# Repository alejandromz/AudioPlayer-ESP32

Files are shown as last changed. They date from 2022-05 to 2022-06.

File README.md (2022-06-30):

# AudioPlayer-ESP32
Proyecto Sistemas Embebidos 2022-1. La documentación del proyecto se puede encontrar en el Wiki asociado a este repositorio. En la parte del código se pueden encontrar 3 carpetas: una con el desarrollo de la placa en Kikad, otra con el código de prueba de módulos individuales y la última con el código final del proyecto.

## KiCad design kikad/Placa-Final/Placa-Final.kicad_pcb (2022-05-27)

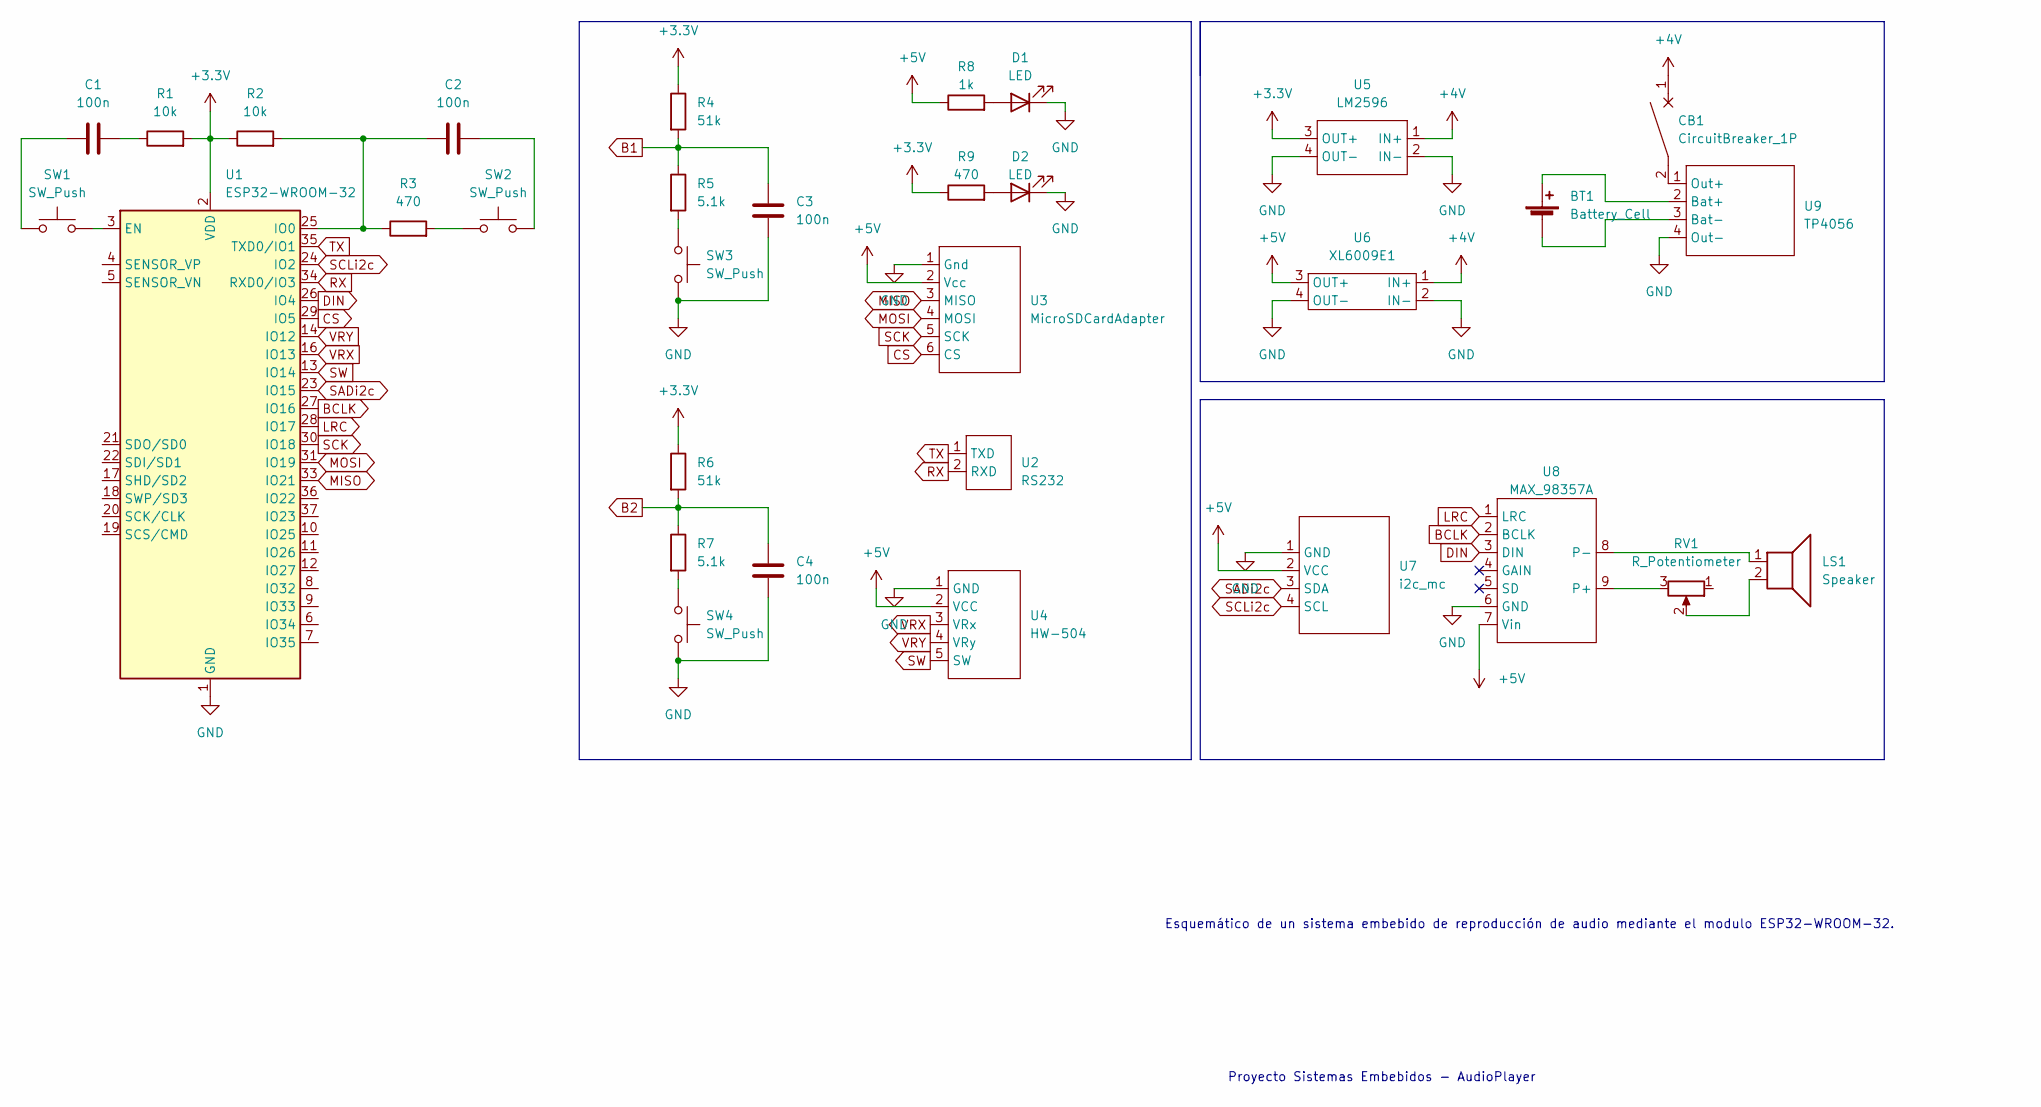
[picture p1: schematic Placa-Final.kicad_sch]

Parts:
BT1: Battery_Cell; PinHeader_1x02_P2.54mm_Vertical
C1, C2, C3, C4: 100n; C_0805_2012Metric_Pad1.18x1.45mm_HandSolder
CB1: CircuitBreaker_1P; SW_DIP_SPSTx01_Slide_9.78x4.72mm_W7.62mm_P2.54mm
D1, D2: LED; LED_D3.0mm
LS1: Speaker; PinHeader_1x02_P2.54mm_Vertical
R1, R2: 10k; R_0805_2012Metric_Pad1.20x1.40mm_HandSolder
R3, R9: 470; R_0805_2012Metric_Pad1.20x1.40mm_HandSolder
R4, R6: 51k; R_0805_2012Metric_Pad1.20x1.40mm_HandSolder
R5, R7: 5.1k; R_0805_2012Metric_Pad1.20x1.40mm_HandSolder
R8: 1k; R_0805_2012Metric_Pad1.20x1.40mm_HandSolder
RV1: R_Potentiometer; Potentiometer_Alps_RK09Y11_Single_Horizontal
SW1, SW2, SW3, SW4: SW_Push; SW_PUSH_6mm_H5mm
U1: ESP32-WROOM-32
U2: RS232; PinHeader_1x02_P2.54mm_Vertical
U3: MicroSDCardAdapter
U4: HW-504
U5: LM2596
U6: XL6009E1
U7: i2c_mc; PinHeader_1x04_P2.54mm_Vertical
U8: MAX_98357A; MAX98357a
U9: TP4056; Tp056

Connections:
+3V3: R1.2, R2.1, R4.1, R6.1, R9.1, U1.2 (VDD), U5.3 (OUT+)
+4V: CB1.1, U5.1 (IN+), U6.1 (IN+)
+5V: R8.1, U3.2 (Vcc), U4.2 (VCC), U6.3 (OUT+), U7.2 (VCC), U8.7 (Vin)
B1: C3.2, R4.2, R5.1
B2: C4.2, R6.2, R7.1
BCLK: U1.27 (IO16), U8.2 (BCLK)
CS: U1.29 (IO5), U3.6 (CS)
DIN: U1.26 (IO4), U8.3 (DIN)
GND: C3.1, C4.1, D1.1 (K), D2.1 (K), SW3.2, SW4.2, U1.1 (GND), U1.15 (GND), U1.38 (GND), U1.39 (GND), U3.1 (Gnd), U4.1 (GND), U5.2 (IN-), U5.4 (OUT-), U6.2 (IN-), U6.4 (OUT-), U7.1 (GND), U8.6 (GND), U9.4 (Out-)
LRC: U1.28 (IO17), U8.1 (LRC)
MISO: U1.33 (IO21), U3.3 (MISO)
MOSI: U1.31 (IO19), U3.4 (MOSI)
unnamed: BT1.1 (+), U9.2 (Bat+)
unnamed: BT1.2 (-), U9.3 (Bat-)
unnamed: C1.1, SW1.1
unnamed: C1.2, R1.1
unnamed: C2.1, R2.2, R3.1, U1.25 (IO0)
unnamed: C2.2, SW2.2
unnamed: CB1.2, U9.1 (Out+)
unnamed: D1.2 (A), R8.2
unnamed: D2.2 (A), R9.2
unnamed: LS1.1, U8.8 (P-)
unnamed: LS1.2, RV1.2
unnamed: R3.2, SW2.1
unnamed: R5.2, SW3.1
unnamed: R7.2, SW4.1
unnamed: RV1.3, U8.9 (P+)
unnamed: SW1.2, U1.3 (EN)
RX: U1.34 (RXD0/IO3), U2.2 (RXD)
SADi2c: U1.23 (IO15), U7.3 (SDA)
SCK: U1.30 (IO18), U3.5 (SCK)
SCLi2c: U1.24 (IO2), U7.4 (SCL)
SW: U1.13 (IO14), U4.5 (SW)
TX: U1.35 (TXD0/IO1), U2.1 (TXD)
VRX: U1.16 (IO13), U4.3 (VRx)
VRY: U1.14 (IO12), U4.4 (VRy)

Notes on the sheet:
Esquemático de un sistema embebido de reproducción de audio mediante el modulo ESP32-WROOM-32.
Proyecto Sistemas Embebidos - AudioPlayer

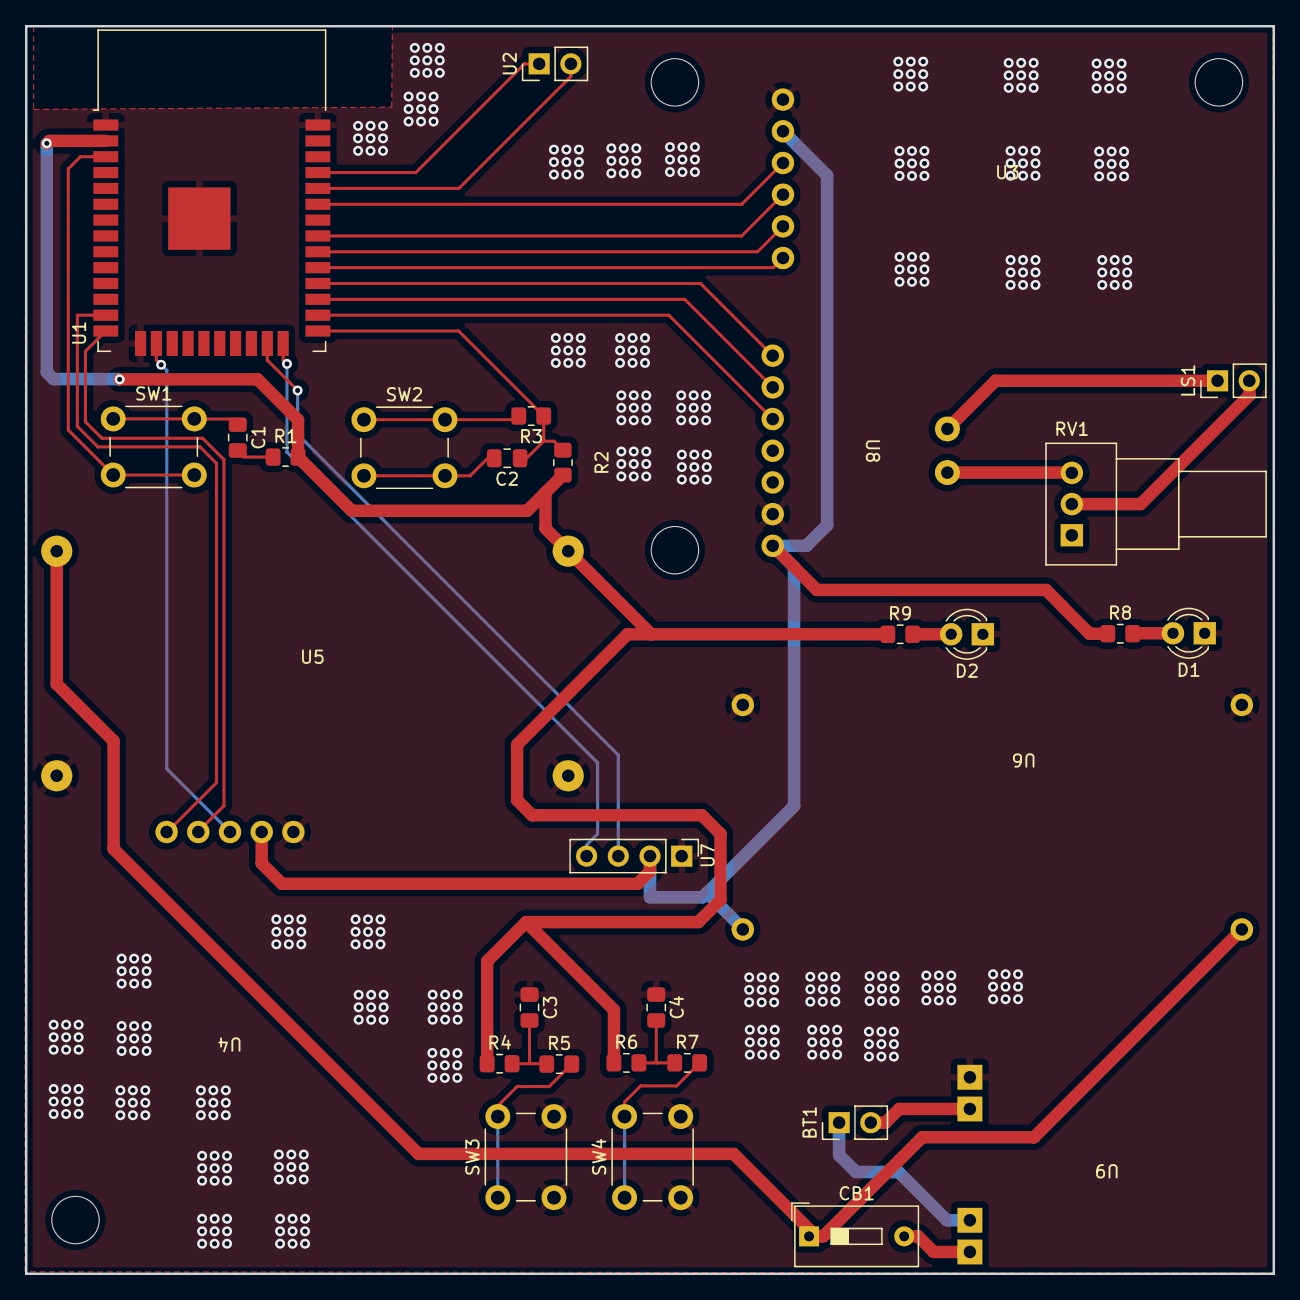
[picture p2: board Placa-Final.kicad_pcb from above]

Board: 2 copper layers, 100.0 x 100.0 mm, 32 parts (0 on the bottom side), 36 nets.

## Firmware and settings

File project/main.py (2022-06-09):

## ---------------------------------------------
# 
# Project: ESP32 Audio Player
# Universidad Nacional de Colombia - Sede Bogotá
# Departamento de Ingeniería Eléctrica y Electrónica
#
# Sistemas Embebidos 2022-1
# Professor: Johnny German Cubides Castro
# 
## ---------------------------------------------

# Import required libraries
from time import sleep_ms, ticks_ms
from machine import I2C, I2S, Pin, ADC, SoftSPI
from i2c_lcd import I2cLcd
from sdcard import SDCard
import os


## Allocate buffer variables
wav_samples = bytearray(1024)
wav_samples_mv = memoryview(wav_samples)


## Define functions
def display_menu(directorio, pos):
    lcd.clear()
    if pos == len(directorio)-1:
        lcd.putstr('{}\n>{}'.format(directorio_dsp[pos-1],directorio_dsp[pos]))
    else:
        lcd.putstr('>{}\n{}'.format(directorio_dsp[pos],directorio_dsp[pos+1]))
    sleep_ms(300)
    

def navigate(pos):
    y_val = y.read()
    if y_val < threshold:
        pos = pos-1
        if pos<0:
            pos=0
    elif y_val > 4095-threshold:
        pos = pos+1
        if pos>len(directorio)-1:
            pos = len(directorio)-1
    return pos
        

def select_dir(directorio, old_dir, pos, state):
    wav = None
    if directorio[pos] == 'Return':
        try:
            lst = old_dir.split('/')
            old_dir=''
            
            if (len(lst) > 2 and lst[0] != '') or len(lst) > 3:
                for item in lst[0:-2]:
                    ## print(item)
                    if item != '':
                        old_dir=old_dir+'/'+item
            else:
                old_dir=owd
        except:
            print('Error')
                
        os.chdir(old_dir)
        directorio = os.listdir()
        if old_dir != owd:
            directorio.append('Return')
        pos = 0
    elif directorio[pos][-4:] == '.wav':
        state = 'play'
        wav_file = old_dir+directorio[pos]
        wav = open(wav_file,'rb')
    else:
        try:
            os.chdir(directorio[pos])
            old_dir=old_dir+directorio[pos]+'/'
            directorio = os.listdir()
            directorio.append('Return')
            pos = 0
        except:
            print('No es un directorio.')
    return directorio, old_dir, pos, state, wav


def play_wav(wav, w_pos, wav_len, state):
    global wav_samples_mv
    if  w_pos < wav_len:
        wav.seek(w_pos)
        wav.readinto(wav_samples_mv)
        num_written = audio_out.write(wav_samples_mv)
        w_pos += num_written
    else:
        state = 'pause'
        w_pos = wav.seek(44)
    return w_pos, state
            
            
def display_wav(directorio, pos, w_pos, wav_len, state):
    lcd.clear()
    lcd.putstr('{}\n{}'.format(directorio[pos][:12], state))
    
    
def play_pause(state):
    if sw.value()==0:
        if state == 'play':
            state = 'pause'
        elif state == 'pause':
            state='play'
        sleep_ms(200)
        
    x_val = x.read()
    if x_val < threshold:
        state = 'menu'
        wav.close()
        
    return state
        
        
## Initialize class instances

# Initialize SDCard object
spisd = SoftSPI(-1,
                miso=Pin(21),
                mosi=Pin(19),
                sck=Pin(18))
sd = SDCard(spisd, Pin(5))

# Initialize I2S object
# sck=Pin(16), ws=Pin(17), sd=Pin(4),
audio_out = I2S(1,
                sck=Pin(25), ws=Pin(26), sd=Pin(4),
                mode=I2S.TX,
                bits=16, 
                format=I2S.MONO,
                rate=16000,
                ibuf=2000)

# Initialize I2C object
DEFAULT_I2C_ADDR = 0X27
# i2c=I2C(scl=Pin(22), sda=Pin(21), freq=400000)
i2c=I2C(scl=Pin(22), sda=Pin(15), freq=400000)
lcd = I2cLcd(i2c, DEFAULT_I2C_ADDR,2,16)

# Initialize joystick
threshold = 500
x = ADC(Pin(32))
y = ADC(Pin(33))
x.atten(ADC.ATTN_11DB)
y.atten(ADC.ATTN_11DB)
sw = Pin(14, Pin.IN, Pin.PULL_UP)


## Initialize SD storage 
vfs=os.VfsFat(sd)
os.mount(vfs, '/sd')
owd = os.getcwd()
old_dir=owd


## Create list of the sd directories
directorio = os.listdir()
directorio_dsp = [st[0:12] for st in directorio]
pos = 0
display_menu(directorio, pos)


## Define initial state
state = 'menu'
wav = None
wav_len = 0
w_pos = 0


## Main loop
while True:
    if state == 'menu':
        old_pos = pos
        pos = navigate(old_pos)
        if pos != old_pos:
            display_menu(directorio, pos)
            sleep_ms(100)
            
        if sw.value()==0:
            directorio, old_dir, pos, state, wav = select_dir(directorio, old_dir, pos, state)
            directorio_dsp = [st[0:12] for st in directorio]
            if state == 'play':
                wav_len = wav.seek(0, 2)
                w_pos = wav.seek(44)
                display_wav(directorio, pos, w_pos, wav_len, state)
            else:
                display_menu(directorio, pos)
            sleep_ms(200)
    elif state == 'play':
        w_pos, state = play_wav(wav, w_pos, wav_len, state)
        state = play_pause(state)
        if state == 'pause':
            display_wav(directorio, pos, w_pos, wav_len, state)
        elif state == 'menu':
            display_menu(directorio, pos)
    elif state == 'pause':
        state = play_pause(state)
        if state == 'play':
            display_wav(directorio, pos, w_pos, wav_len, state)
        elif state == 'menu':
            display_menu(directorio, pos)
    else:
        print('State errror.')
            
    
    

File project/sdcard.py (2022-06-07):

"""
MicroPython driver for SD cards using SPI bus.
Requires an SPI bus and a CS pin.  Provides readblocks and writeblocks
methods so the device can be mounted as a filesystem.
Example usage on pyboard:
    import pyb, sdcard, os
    sd = sdcard.SDCard(pyb.SPI(1), pyb.Pin.board.X5)
    pyb.mount(sd, '/sd2')
    os.listdir('/')
Example usage on ESP8266:
    import machine, sdcard, os
    sd = sdcard.SDCard(machine.SPI(1), machine.Pin(15))
    os.mount(sd, '/sd')
    os.listdir('/')
"""

from micropython import const
import time


_CMD_TIMEOUT = const(100)

_R1_IDLE_STATE = const(1 << 0)
# R1_ERASE_RESET = const(1 << 1)
_R1_ILLEGAL_COMMAND = const(1 << 2)
# R1_COM_CRC_ERROR = const(1 << 3)
# R1_ERASE_SEQUENCE_ERROR = const(1 << 4)
# R1_ADDRESS_ERROR = const(1 << 5)
# R1_PARAMETER_ERROR = const(1 << 6)
_TOKEN_CMD25 = const(0xFC)
_TOKEN_STOP_TRAN = const(0xFD)
_TOKEN_DATA = const(0xFE)


class SDCard:
    def __init__(self, spi, cs, baudrate=1320000):
        self.spi = spi
        self.cs = cs

        self.cmdbuf = bytearray(6)
        self.dummybuf = bytearray(512)
        self.tokenbuf = bytearray(1)
        for i in range(512):
            self.dummybuf[i] = 0xFF
        self.dummybuf_memoryview = memoryview(self.dummybuf)

        # initialise the card
        self.init_card(baudrate)

    def init_spi(self, baudrate):
        try:
            master = self.spi.MASTER
        except AttributeError:
            # on ESP8266
            self.spi.init(baudrate=baudrate, phase=0, polarity=0)
        else:
            # on pyboard
            self.spi.init(master, baudrate=baudrate, phase=0, polarity=0)

    def init_card(self, baudrate):

        # init CS pin
        self.cs.init(self.cs.OUT, value=1)

        # init SPI bus; use low data rate for initialisation
        self.init_spi(100000)

        # clock card at least 100 cycles with cs high
        for i in range(16):
            self.spi.write(b"\xff")

        # CMD0: init card; should return _R1_IDLE_STATE (allow 5 attempts)
        for _ in range(5):
            if self.cmd(0, 0, 0x95) == _R1_IDLE_STATE:
                break
        else:
            raise OSError("no SD card")

        # CMD8: determine card version
        r = self.cmd(8, 0x01AA, 0x87, 4)
        if r == _R1_IDLE_STATE:
            self.init_card_v2()
        elif r == (_R1_IDLE_STATE | _R1_ILLEGAL_COMMAND):
            self.init_card_v1()
        else:
            raise OSError("couldn't determine SD card version")

        # get the number of sectors
        # CMD9: response R2 (R1 byte + 16-byte block read)
        if self.cmd(9, 0, 0, 0, False) != 0:
            raise OSError("no response from SD card")
        csd = bytearray(16)
        self.readinto(csd)
        if csd[0] & 0xC0 == 0x40:  # CSD version 2.0
            self.sectors = ((csd[8] << 8 | csd[9]) + 1) * 1024
        elif csd[0] & 0xC0 == 0x00:  # CSD version 1.0 (old, <=2GB)
            c_size = csd[6] & 0b11 | csd[7] << 2 | (csd[8] & 0b11000000) << 4
            c_size_mult = ((csd[9] & 0b11) << 1) | csd[10] >> 7
            self.sectors = (c_size + 1) * (2 ** (c_size_mult + 2))
        else:
            raise OSError("SD card CSD format not supported")
        # print('sectors', self.sectors)

        # CMD16: set block length to 512 bytes
        if self.cmd(16, 512, 0) != 0:
            raise OSError("can't set 512 block size")

        # set to high data rate now that it's initialised
        self.init_spi(baudrate)

    def init_card_v1(self):
        for i in range(_CMD_TIMEOUT):
            self.cmd(55, 0, 0)
            if self.cmd(41, 0, 0) == 0:
                self.cdv = 512
                # print("[SDCard] v1 card")
                return
        raise OSError("timeout waiting for v1 card")

    def init_card_v2(self):
        for i in range(_CMD_TIMEOUT):
            time.sleep_ms(50)
            self.cmd(58, 0, 0, 4)
            self.cmd(55, 0, 0)
            if self.cmd(41, 0x40000000, 0) == 0:
                self.cmd(58, 0, 0, 4)
                self.cdv = 1
                # print("[SDCard] v2 card")
                return
        raise OSError("timeout waiting for v2 card")

    def cmd(self, cmd, arg, crc, final=0, release=True, skip1=False):
        self.cs(0)

        # create and send the command
        buf = self.cmdbuf
        buf[0] = 0x40 | cmd
        buf[1] = arg >> 24
        buf[2] = arg >> 16
        buf[3] = arg >> 8
        buf[4] = arg
        buf[5] = crc
        self.spi.write(buf)

        if skip1:
            self.spi.readinto(self.tokenbuf, 0xFF)

        # wait for the response (response[7] == 0)
        for i in range(_CMD_TIMEOUT):
            self.spi.readinto(self.tokenbuf, 0xFF)
            response = self.tokenbuf[0]
            if not (response & 0x80):
                # this could be a big-endian integer that we are getting here
                for j in range(final):
                    self.spi.write(b"\xff")
                if release:
                    self.cs(1)
                    self.spi.write(b"\xff")
                return response

        # timeout
        self.cs(1)
        self.spi.write(b"\xff")
        return -1

    def readinto(self, buf):
        self.cs(0)

        # read until start byte (0xff)
        for i in range(_CMD_TIMEOUT):
            self.spi.readinto(self.tokenbuf, 0xFF)
            if self.tokenbuf[0] == _TOKEN_DATA:
                break
            time.sleep_ms(1)
        else:
            self.cs(1)
            raise OSError("timeout waiting for response")

        # read data
        mv = self.dummybuf_memoryview
        if len(buf) != len(mv):
            mv = mv[: len(buf)]
        self.spi.write_readinto(mv, buf)

        # read checksum
        self.spi.write(b"\xff")
        self.spi.write(b"\xff")

        self.cs(1)
        self.spi.write(b"\xff")

    def write(self, token, buf):
        self.cs(0)

        # send: start of block, data, checksum
        self.spi.read(1, token)
        self.spi.write(buf)
        self.spi.write(b"\xff")
        self.spi.write(b"\xff")

        # check the response
        if (self.spi.read(1, 0xFF)[0] & 0x1F) != 0x05:
            self.cs(1)
            self.spi.write(b"\xff")
            return

        # wait for write to finish
        while self.spi.read(1, 0xFF)[0] == 0:
            pass

        self.cs(1)
        self.spi.write(b"\xff")

    def write_token(self, token):
        self.cs(0)
        self.spi.read(1, token)
        self.spi.write(b"\xff")
        # wait for write to finish
        while self.spi.read(1, 0xFF)[0] == 0x00:
            pass

        self.cs(1)
        self.spi.write(b"\xff")
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
